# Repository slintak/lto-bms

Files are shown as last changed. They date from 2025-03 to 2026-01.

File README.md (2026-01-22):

# LTO / Na-ion Battery Management System (BMS)

This project is an open-source Battery Management System (BMS) designed for a 1S
Lithium Titanate (LTO) battery pack, with experimental support for 1S Sodium-ion
(Na-ion) cells. It is intended for low-power applications,
specifically the [Meshtastic project](https://meshtastic.org), where expected
discharge currents are in the tens of milliamps, and charging is usually
handled by a solar panel with MPPT, reaching up to several hundred milliamps.

More details about the project can be found here:
[LTO BMS Development Notes](https://uart.cz/en/2557/lto-bms-development-notes/).

## Understanding LTO Batteries

LTO batteries, or Lithium Titanium Oxide batteries, have one enormous
advantage — they can be charged and discharged at sub-zero temperatures. This
makes them ideal for applications such as weather stations, Meshtastic nodes,
and other outdoor electronics.

LTO batteries have lower energy density than other types, so less Ah fits into
the same package. They have a lower operating voltage, a minimum of 1.5 V
(some sources and manufacturers report 1.7 V), and a maximum of 2.8 V
(again, you may read 2.9 V elsewhere). They are chemically very stable, posing
no risks of swelling, fires, or explosions like Li-Ion or Li-Pol cells. Some
manufacturers claim that LTO can be discharged to 0 V and overcharged above 3 V
without exploding or getting damaged.

However, for the average hobbyist, usage can be a bit more complicated because
LTO batteries have a lower voltage than standard Li-Ion or Li-Pol batteries,
and there is no available electronic protection for single-cell LTO. That’s why
I set out to design my own solution that, in addition to OVLO/UVLO/OC, also
continuously measures the cell parameters and communicates them over I2C.

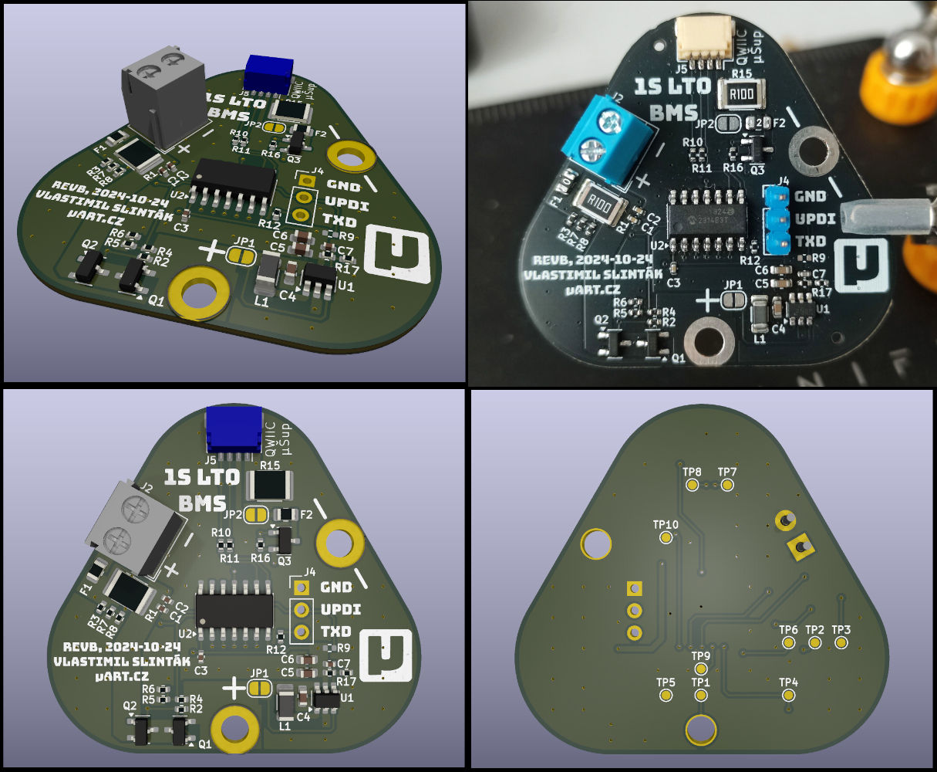
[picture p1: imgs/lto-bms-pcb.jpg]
Custom PCB for the LTO BMS

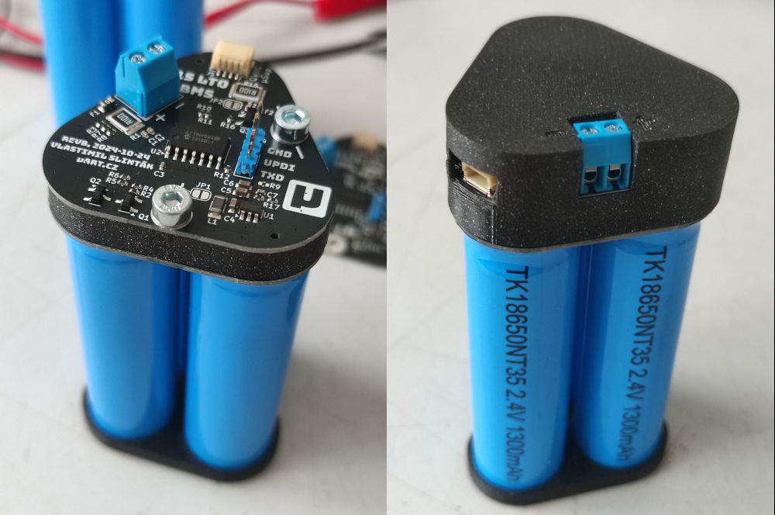
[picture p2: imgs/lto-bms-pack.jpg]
LTO 1S3P battery pack with BMS


## Features

- Supports 1S LTO battery configuration (tested and stable).
- Supports 1S Na-ion battery configuration (experimental; needs more testing).
- Under-voltage (UVLO) protection.
- Over-voltage (OVLO) protection.
- Over-current (OCLO) protection.
- Metrics available over I2C (the interface immitates INA260 IC).
- Designed for low-power applications, up to 1 A charging and discharging.
- Uses ATTiny824 with an integrated ADC, I2C, and temperature sensor.

## Hardware Requirements

- Custom PCB designed for LTO BMS (designed by the author).
- 1S LTO battery pack.
- USB-UART converter for programming.

## Software Requirements

- GCC toolchain for AVR (AVR-GCC, [pymcuprog](https://github.com/microchip-pic-avr-tools/pymcuprog), etc.)
- Python 3 (for EEPROM configuration and logging tools)
- Docker (optional, for storing metrics to InfluxDB and Grafana during development and long-term testing)

## Compilation and Flashing

Ensure you have the necessary tools installed. The code was developed under
Ubuntu OS, so the following commands should work on any Debian-based system.

```
sudo apt update
sudo apt install -y gcc-avr python3-pip

# Installing Python packages in a virtual environment is recommended.
pip3 install -r requirements.txt
```

To build the firmware, run:

```
make
# Or with enabled debug logging
make DEBUG=1
```

By default, `make` builds both chemistries (LTO and NAION). To build or flash a
single chemistry, set `CHEMISTRY`:

```
make CHEMISTRY=LTO
make CHEMISTRY=NAION
make flash CHEMISTRY=NAION
```

Note: Na-ion support is experimental and requires more validation on hardware.

The microcontroller can be programmed using `pymcuprog` with a USB-UART
converter. The RX and TX lines of the converter should be connected via a 1kΩ
resistor, with the RX line then connected to the UPDI on the BMS PCB. To flash
the firmware, use:

```
make fuses  # Run only once.
make flash
```

To configure EEPROM settings, use the provided Python script:

```
python eeprom.py --sn 7 --temp-offset 5
objcopy --input-target=binary --output-target=ihex --change-addresses=0x810000 eeprom.bin eeprom.hex
pymcuprog write -f eeprom.hex -t uart -d attiny824 -u [COM]
```

or by using a Makefile target:

```
make eeprom SN=7 TO=5
```

## EEPROM Configuration

The ATTiny824 has 128 B of EEPROM. The firmware uses this memory to store
configuration settings such as the serial number, voltage and current limits,
and more. For fine-tuning your BMS, you can change any parameter with the
`eeprom.py` tool:

```
$ python3 eeprom.py --help
usage: eeprom.py [-h] --sn SN [--temp-offset TEMP_OFFSET] [--ovlo-cutoff OVLO_CUTOFF] [--ovlo-release OVLO_RELEASE]
                 [--uvlo-release UVLO_RELEASE] [--uvlo-cutoff UVLO_CUTOFF] [--max-current MAX_CURRENT]
                 [--oclo-timeout OCLO_TIMEOUT] [-f FILE]

EEPROM configuration generator for LTO-BMS firmware.

options:
  -h, --help            show this help message and exit
  --sn SN               Unique serial number of the BMS.
  --temp-offset TEMP_OFFSET
                        Temperature offset for the internal sensor.
  --ovlo-cutoff OVLO_CUTOFF
                        Over-voltage cutoff. Unit: mV.
  --ovlo-release OVLO_RELEASE
                        Over-voltage release. Unit: mV.
  --uvlo-release UVLO_RELEASE
                        Under-voltage release. Unit: mV.
  --uvlo-cutoff UVLO_CUTOFF
                        Under-voltage cutoff. Unit: mV.
  --max-current MAX_CURRENT
                        Maximum allowed current. Unit: mA.
  --oclo-timeout OCLO_TIMEOUT
                        Time to hold over-current lockout. Unit: s.
  -f FILE, --file FILE  Filename to write binary data.
```

## Logging

For long-term logging and testing, you can use the BMS log to store all metrics
in InfluxDB. To do this, use the `log.py` tool. First, prepare your `.env` file
with your InfluxDB bucket, token, and URL, then run:

```
python3 log.py [COM]
```

## License

This project is open-source under the MIT License. Feel free to contribute!

## Contact

For any questions or contributions, visit [uart.cz](https://uart.cz/en) or open
an issue in the repository.

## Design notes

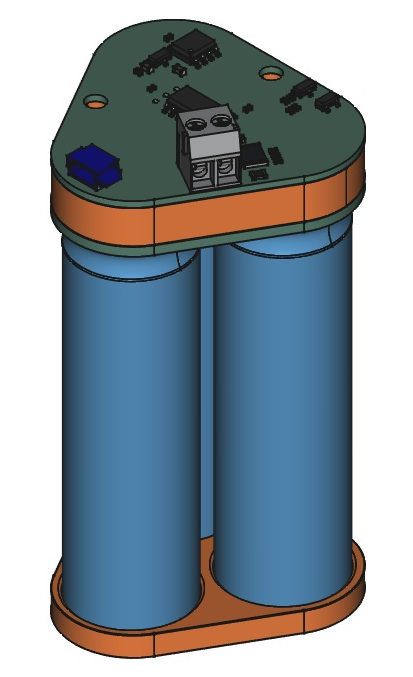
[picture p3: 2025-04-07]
docs/LTO-BMS-revB-overview.png

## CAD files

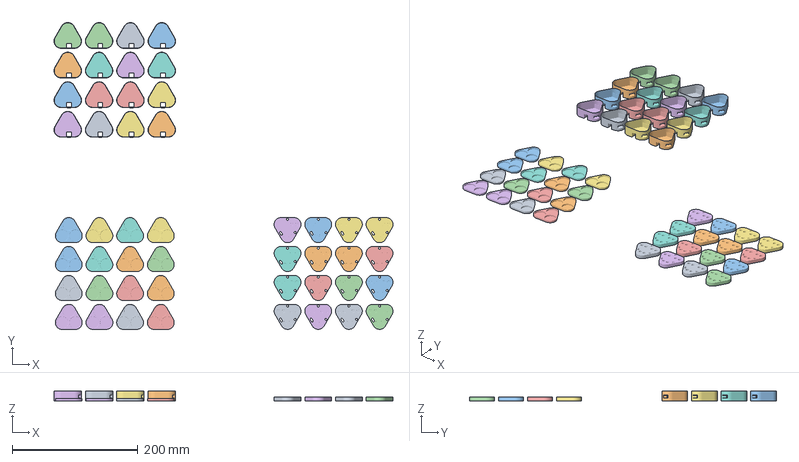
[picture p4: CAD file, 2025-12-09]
3d_model/LTO-BMS-revB-enclosure.3mf
539.2 x 488.1 x 15.8 mm
LTO-BMS-revB-LTO 1S3P Pack v133D Printables_2
LTO-BMS-revB-LTO 1S3P Pack v133D Printables_3
BMS_Insert

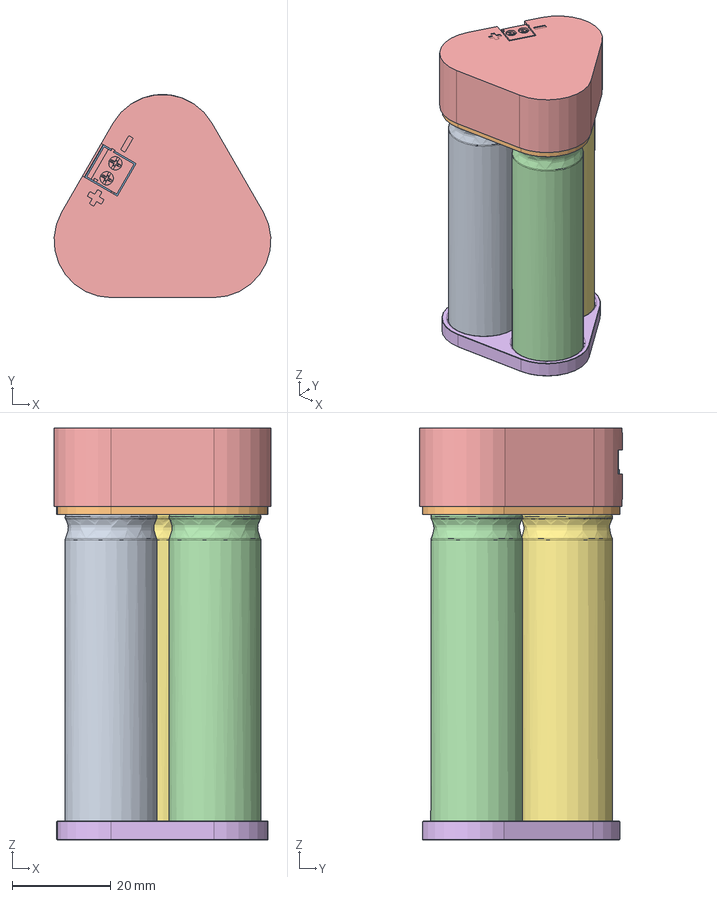
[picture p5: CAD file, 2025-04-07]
3d_model/LTO-BMS-revB.FCStd
43.8 x 41.1 x 83.3 mm
(Unsaved) (1)
(Unsaved) (1)001
(Unsaved) (1)002
(Unsaved) (1)004
(Unsaved) (1)005
(Unsaved) (1)006
(Unsaved) (1)008
(Unsaved) (1)009
(Unsaved) (1)010
lto-pack_PCB
SOT-23-3
Fuse_0805_2012Metric
R_0402_1005Metric
R_0402_1005Metric001
SOT_23
R_0402_1005Metric002
R_0402_1005Metric003
R_0402_1005Metric004
R_0402_1005Metric005
C_0402_1005Metric
SOIC_14_39x87mm_P127mm
C_0603_1608Metric
SOIC_8_39x49mm_P127mm
C_0603_1608Metric001
R_0402_1005Metric006
R_1812_4532Metric
R_0402_1005Metric007
C_0402_1005Metric001
97m9695_1776275-2
C_0402_1005Metric002
C_0402_1005Metric003
SOT-23-004
SM04B-SRSS
C_0402_1005Metric004
lto-bms_PCB
Insert
Top_Cover
Bottom_Cover

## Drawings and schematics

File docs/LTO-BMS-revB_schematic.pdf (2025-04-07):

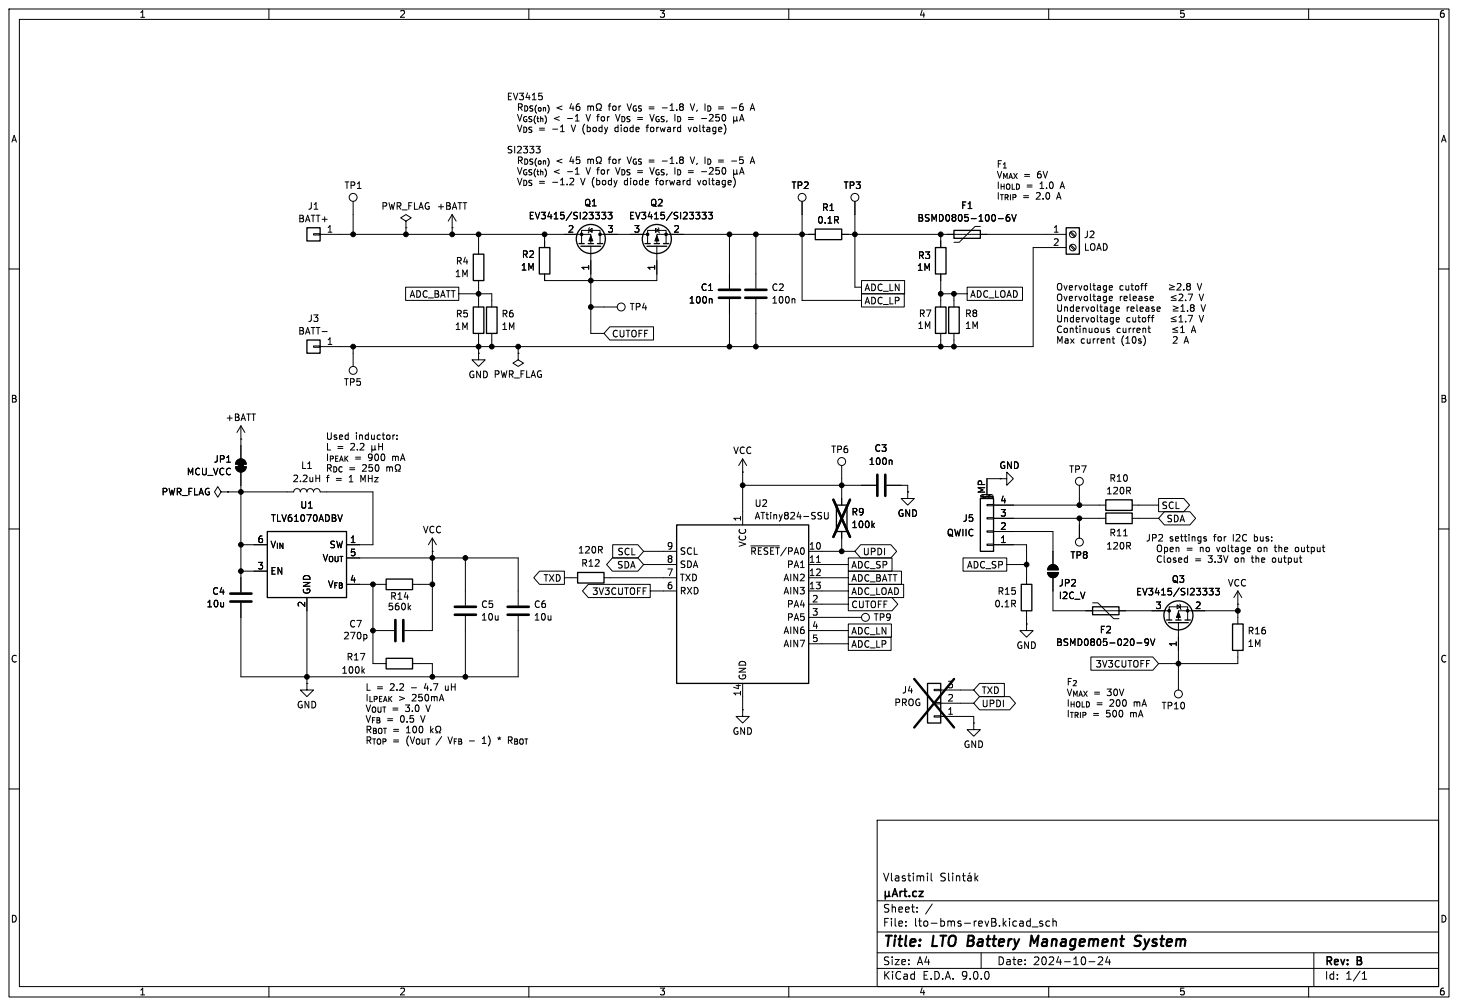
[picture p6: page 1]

I_{TRIP} = 2.0 A Used inductor: L = 2.2 þÿµH

I_{PEAK} = 900 mA R_{DC} = 250 þÿm©
f = 1 MHz

2 SW 1 V_{OUT} 5 V_{FB}4 U1 TLV61070ADBV GND

R_{TOP} = (V_{OUT} / V_{FB}- 1) * R_{BOT}

Id: 1/1 Title: LTO Battery Management System

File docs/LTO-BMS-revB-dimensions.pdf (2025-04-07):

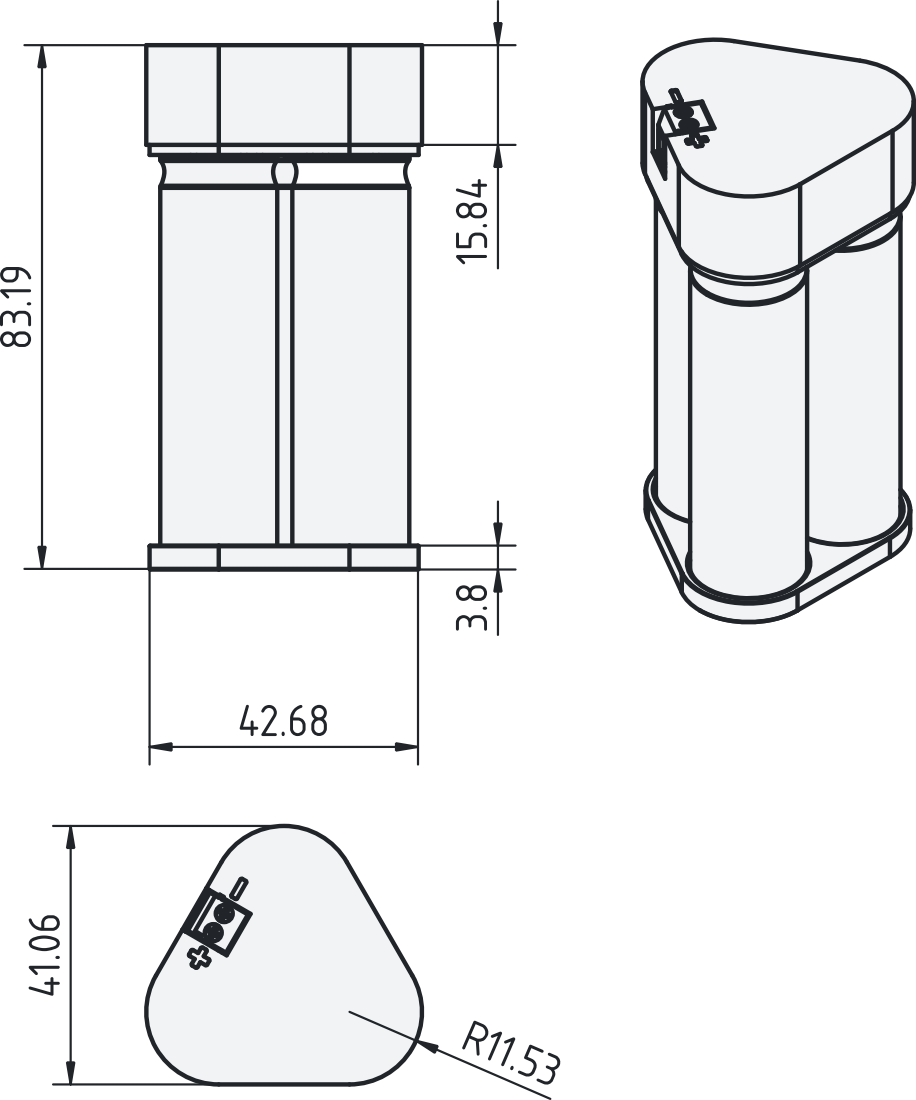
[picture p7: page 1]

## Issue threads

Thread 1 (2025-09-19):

the Q1 transistor burned out, do I need to reprogram the uP

spairo1741, 2025-09-19:
Hi, I don't know where to write this. I have two µArt.cz 1S3P LTO batteries with BMS. In one of them, the Q1 transistor burned out. Is replacing this transistor enough or do I need to reprogram the uP? I'm asking because there's only 1.2V on pin 2 of the uP CUTOFF.

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]

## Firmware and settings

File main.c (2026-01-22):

#include <stdlib.h>
#include <string.h>

#include <avr/io.h>
#include <avr/interrupt.h>
#include <avr/wdt.h>
#include <util/delay.h>

#include "adc.h"
#include "config.h"
#include "gpio.h"
#include "uart.h"
#include "twi.h"

// Minimum voltage difference (in mV) required between load and battery
// for the charging process to begin when UVLO is active. The cutoff protection
// will only be disabled if the load voltage is at least this much higher than
// the battery voltage.
#define UVLO_MIN_VOLTAGE_DIFFERENCE 50 // mV

// Minimum voltage difference (in mV) required between load and battery
// for the discharging process to begin when OVLO is active. The cutoff
// protection will only be disabled if the load voltage is at least this much
// higher than the battery voltage.
#define OVLO_MIN_VOLTAGE_DIFFERENCE 50 // mV

// How often to print measurements to stdout. In seconds.
#define MEASUREMENT_LOG_INTERVAL 60


#define BMS_CHANGE_STATE(ns) do { bms_state = ns; bms_state_transition_timestamp = uptime; } while(0)

static bms_states_e bms_state = BMS_STATE_INVALID;
static uint32_t bms_state_transition_timestamp = 0;

static bms_eeprom_config_t bms_config;
static uint32_t energy_discharge = 0;
static uint32_t energy_charge = 0;
static int32_t charge = 0;
static bool tick = false;
static uint32_t uptime = 0;
static adc_measurement_t *adc;

static uint32_t next_log_message = 0;

ISR(RTC_PIT_vect) {
    tick = true;
    uptime++;

    // Clear flag.
    RTC.PITINTFLAGS = RTC_PI_bm;
}

/**
 * Initialize RTC.
 * This will run 1.024 kHz clock with 1024 prescaler. We will
 * have RTC PIT interrput every 1 second. This will be our wake-up
 * source from the standby sleep.
 */
void RTC_init(void) {
    // 1.024 kHz internal crystal oscillator.
    RTC.CLKSEL = RTC_CLKSEL_INT1K_gc;
    // Periodic Interrupt: enabled
    RTC.PITINTCTRL = RTC_PI_bm;
    while(RTC.PITSTATUS & RTC_CTRLABUSY_bm);

    RTC.PITCTRLA = RTC_PERIOD_CYC1024_gc | RTC_PITEN_bm;
}

void RTC_start(void) {
    RTC.PITCTRLA |= RTC_PITEN_bm;
}

void RTC_stop(void) {
    RTC.PITCTRLA &= ~RTC_PITEN_bm;
}

void PORT_init(void) {
    BMS_CUTOFF_ON();
    BMS_CUTOFF_3V3_ON();

    // When debug (UART) is needed.
    PORTB.DIR |= BMS_UART_TX;

    // Disable digital input buffer for all analog inputs.
    // This should reduce consumption a little.
    PORTA.PIN2CTRL = PORT_ISC_INPUT_DISABLE_gc;
    PORTA.PIN3CTRL = PORT_ISC_INPUT_DISABLE_gc;
    PORTA.PIN6CTRL = PORT_ISC_INPUT_DISABLE_gc;
    PORTA.PIN7CTRL = PORT_ISC_INPUT_DISABLE_gc;
    PORTB.PIN0CTRL = PORT_ISC_INPUT_DISABLE_gc;
    PORTB.PIN1CTRL = PORT_ISC_INPUT_DISABLE_gc;
}

/**
 * Enter a standby sleep mode.
 * Only the RTC PIT can wake us.
 */
void standby_enable(void) {
    SLPCTRL.CTRLA = SLPCTRL_SMODE_STDBY_gc | SLPCTRL_SEN_bm;
    __asm__ __volatile__ ("SLEEP");
}

int main(void) {
    // Watchdog should be enabled automatically by fuses.
    // They are in the `fuses.hex` file, use `make fuses` to write them.

    // Configure clock with 16x prescaler and enable prescaler division.
    // This should result in 20 / 16 = 1.25 MHz CPU clock. This should result
    // in lower consumption and more stable operation under lower voltages.
    CCP = CCP_IOREG_gc;
    CLKCTRL.MCLKCTRLB = CLKCTRL_PDIV_16X_gc | CLKCTRL_PEN_bm;

    PORT_init();

    RTC_init();
    RTC_start();

    adc_init();
    adc_start();

    TWI_init();
    twi_registers_t *twi_registers = TWI_get_registers();

    sei();

    LOG_INIT(9600);
    DEBUG("Up and running.\n");

    // Turn on cutoff (turn off voltage on the ouput)
    BMS_CUTOFF_ON();
    BMS_CUTOFF_3V3_ON();

    eeprom_config_init(&bms_config);
    BMS_CHANGE_STATE(BMS_STATE_IDLE);

    while(1) {
        if(!tick) {
            goto main_continue;
        }

        if(!adc_get_measurements(&adc)) {
            DEBUG("Failed to get new measurement!\n");
            goto main_error;
        }

        int32_t current = ADC_TO_CURRENT(adc->current);
        uint32_t battery = ADC_TO_VOLTAGE(adc->battery);
        uint32_t load = ADC_TO_VOLTAGE(adc->load);
        uint32_t temperature = adc_to_temperature(adc->temperature);

        // Current values from -2 to +2 mA are most probably noise on ADC.
        // These will be ignored. This will introduce a small error in our
        // measurement.
        current = (abs(current) > 2) ? current : 0;

        // Current in mA added every second to a total charge in mAs.
        // To calculate mAh later, we will divide the sum by `3600`.
        charge += current;

        // Calculate total discharged/charged energy since last reset.
        if(current > 0) {
            energy_discharge += current * battery / 1000;
        } else {
            energy_charge += abs(current) * battery / 1000;
        }

        switch(bms_state) {
        case BMS_STATE_IDLE:
        case BMS_STATE_CHARGING:
        case BMS_STATE_DISCHARGING:
            if(battery <= bms_config.uvlo_cutoff) {
                BMS_CHANGE_STATE(BMS_STATE_UVLO);
            } else if(battery >= bms_config.ovlo_cutoff) {
                BMS_CHANGE_STATE(BMS_STATE_OVLO);
            } else if(current > bms_config.max_current) {
                BMS_CHANGE_STATE(BMS_STATE_OCLO);
            } else {
                BMS_CUTOFF_OFF();
                BMS_CUTOFF_3V3_OFF();
                if(current > 0) {
                    BMS_CHANGE_STATE(BMS_STATE_DISCHARGING);
                } else if(current < 0) {
                    BMS_CHANGE_STATE(BMS_STATE_CHARGING);
                } else {
                    BMS_CHANGE_STATE(BMS_STATE_IDLE);
                }
            }
            break;

        case BMS_STATE_UVLO:
            if(battery >= bms_config.uvlo_release) {
                BMS_CHANGE_STATE(BMS_STATE_IDLE);
            } else {
                // Check if the load-side voltage is higher than the battery
                // voltage. If so, the charging process can begin, and we need
                // to disable the cutoff protection.
                // Only disable the cutoff if the load voltage is at least
                // 50 mV higher than the battery voltage.
                int32_t vdiff = (int32_t)load - battery;
                if(vdiff > UVLO_MIN_VOLTAGE_DIFFERENCE) {
                    BMS_CUTOFF_OFF();
                    BMS_CUTOFF_3V3_OFF();
                } else {
                    BMS_CUTOFF_ON();
                    BMS_CUTOFF_3V3_ON();
                }
            }
            break;

        case BMS_STATE_OVLO:
            if(battery <= bms_config.ovlo_release) {
                BMS_CHANGE_STATE(BMS_STATE_IDLE);
            } else {
                // Check if the load-side voltage is lower than the battery
                // voltage. If so, the discharging process can begin, and we need
                // to disable the cutoff protection.
                // Only disable the cutoff if the load voltage is at least
                // 50 mV lower than the battery voltage.
                int32_t vdiff = (int32_t)battery - load;
                if(vdiff > OVLO_MIN_VOLTAGE_DIFFERENCE) {
                    BMS_CUTOFF_OFF();
                    BMS_CUTOFF_3V3_OFF();
                } else if(vdiff < -5) {
                    BMS_CUTOFF_ON();
                    // Keep 3.3V output on, discharging is OK while in OVLO.
                    BMS_CUTOFF_3V3_OFF();
                }
            }
            break;

        case BMS_STATE_OCLO:
            // Release the over-current event only after a specified time period.
            if((uptime - bms_state_transition_timestamp) > bms_config.oclo_timeout) {
                BMS_CUTOFF_OFF();
                BMS_CUTOFF_3V3_OFF();
                BMS_CHANGE_STATE(BMS_STATE_IDLE);
            } else {
                BMS_CUTOFF_ON();
                BMS_CUTOFF_3V3_ON();
            }
        break;

        case BMS_STATE_INVALID:
        case BMS_STATE_ERR:
        default:
            DEBUG("INVALID STATE: %u!\n", bms_state);
            goto main_error;
        }

        // Update new measured values into the registers of the "INA260" interface.
        twi_registers->ina260.current = HTONS((int16_t)current / 1.25);
        twi_registers->ina260.voltage = HTONS((uint16_t)battery / 1.25);
        twi_registers->ina260.power = HTONS((uint16_t)((abs(current) * battery) / 10000));

        if(uptime >= next_log_message) {
            LOG(BMS_LOG_TAG ",id=%04X uptime=%lui,v_batt=%lui,v_load=%lui,current=%ldi,",
                bms_config.serial_number,
                uptime,
                battery,
                load,
                current
            );

            LOG("E_dis=%lui,E_chg=%lui,charge=%ldi,temp=%lui,gain=%ui,state=\"%s\"\n",
                energy_discharge / 3600,
                energy_charge / 3600,
                charge / 3600,
                temperature + bms_config.temp_offset,
                1 << adc_get_gain(),
                bms_state_str[bms_state]
            );

            next_log_message = next_log_message + MEASUREMENT_LOG_INTERVAL;
            _delay_ms(5); // Small delay for UART to transmit all data.
        }

        tick = false;
        wdt_reset();
        adc_start();

main_continue:
        standby_enable();
    }

main_error:
    BMS_CUTOFF_ON();
    BMS_CUTOFF_3V3_ON();
    DEBUG("Main loop finished!\n");
    while(1) {
        _delay_ms(1000);
    }
    return 0;
}

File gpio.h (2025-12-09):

#ifndef __BMS_GPIO_H__
#define __BMS_GPIO_H__

#define BMS_ADC_SP   ADC_MUXPOS_AIN1_gc  // PA1
#define BMS_ADC_BATT ADC_MUXPOS_AIN2_gc  // PA2
#define BMS_ADC_OUT  ADC_MUXPOS_AIN3_gc  // PA3
#define BMS_CUTOFF   PIN4_bm
#define BMS_CUTOFF_3V3 PIN5_bm           // PA5
#define BMS_ADC_BN   ADC_MUXNEG_AIN6_gc  // PA6
#define BMS_ADC_BP   ADC_MUXPOS_AIN7_gc  // PA7
#define BMS_IIC_SCL  PIN0_bm  // PB0
#define BMS_IIC_SDA  PIN1_bm  // PB1
#define BMS_UART_TX  PIN2_bm  // PB2
#define BMS_TP9      PIN3_bm  // PB3
#define BMS_ADC_TEMPSENSE ADC_MUXPOS_TEMPSENSE_gc

// Turn on or off the main BMS output on the screw terminal.
#define BMS_CUTOFF_ON() do { PORTA.DIRCLR |= BMS_CUTOFF; } while(0)
#define BMS_CUTOFF_OFF() do { PORTA.DIRSET |= BMS_CUTOFF; PORTA.OUTSET = BMS_CUTOFF; } while(0)

// Turn on or off the 3.3 V output on the QWIIC connector.
#define BMS_CUTOFF_3V3_ON() do { PORTA.DIRCLR |= BMS_CUTOFF_3V3; } while(0)
#define BMS_CUTOFF_3V3_OFF() do { PORTA.DIRSET |= BMS_CUTOFF_3V3; PORTA.OUTCLR = BMS_CUTOFF_3V3; } while(0)

#define HTONS(A) ((((uint16_t)(A) & 0xff00) >> 8) | (((uint16_t)(A) & 0x00ff) << 8))

#endif

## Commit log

2025-03-01 Basic version of the BMS firmware for PCB revision B
2025-04-07 Added datasheet for the LTO BMS in LaTeX
2025-04-07 Added 3D model and 3mf project for enclosure
    [LTO-BMS-revB-enclosure.3mf, LTO-BMS-revB.FCStd]
2025-04-10 Removed unused BMS state
2025-04-10 Added "Charging" section to the datasheet
    * Document revision 2
    * New charging section
    * New graph showing charging process from a constant-voltage source
    * Fixed formatting
    * Fixed wrong data in the self-consumption graph
2025-12-09 Updated 3D printed parts for revision C
    [LTO-BMS-revB-enclosure.3mf]
2025-12-09 Switched Docker image to ghcr.io
    Also, new Debian image is Trixie and has avr-gcc with support for
    ATTiny 0/1/2-series. No need to customize it anymore.
2025-12-09 Support for revision C BMS, do not use with revision B
    Different pinout for CUTTOF_3V3 signal
    Opposite logic for the main CUTOFF signal
    Fixed few minor issues
    [gpio.h, main.c]
2026-01-22 Add compile-time chemistry selection and dual builds
    - add LTO/NAION chemistry define and select ADC reference at compile time
    - split build outputs and object dirs per chemistry/version to avoid cross-contamination
    - default make now builds both chemistries; flash builds selected target
    - add chemistry-aware EEPROM defaults to eeprom.py
    - unify log tag selection via compile-time chemistry
    [adc.c, adc.h, eeprom.py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]
